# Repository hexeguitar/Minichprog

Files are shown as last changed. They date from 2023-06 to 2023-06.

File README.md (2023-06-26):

# Minichprog
### ESP32-S2 based programmer/debugger for the WCH CH32V003 series MCU.  
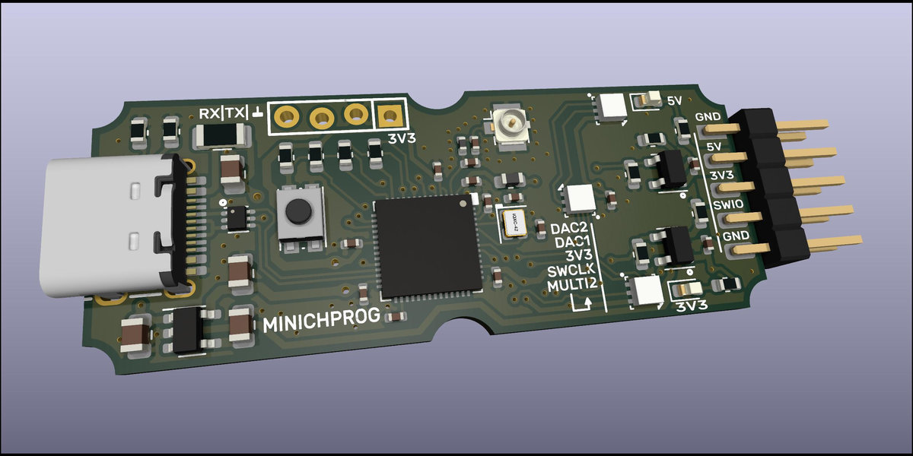
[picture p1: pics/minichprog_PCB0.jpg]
Minichprog
  
Hardware compatible with CNLohr's ESP32-S2 ch32v003 programmer:  
https://github.com/cnlohr/cnhardware/tree/master/esp32s2-funprog  
Firmware and flashing instructions availble here:  
https://github.com/cnlohr/esp32s2-cookbook/tree/master/ch32v003programmer

Differences:
- 500mA polyfuse on the VBUS rail
- USB protection IC
- Current limited power switches
- 5V and 3.3V present led indicators
- smaller footprint, fits into the "USB dongle" 
  acrylic enclosure (same as original WCHLinkE)
- U.FL connector for external WiFI antenna

PCB is 4 layer, designed using KiCAD7. Gerbers in ZIP file are included as well as HTML BOM.  

--- 
Pictures below show rev A, which had additional target discharge option. It was not necessary since the BL2555 power switches have that feature built in.
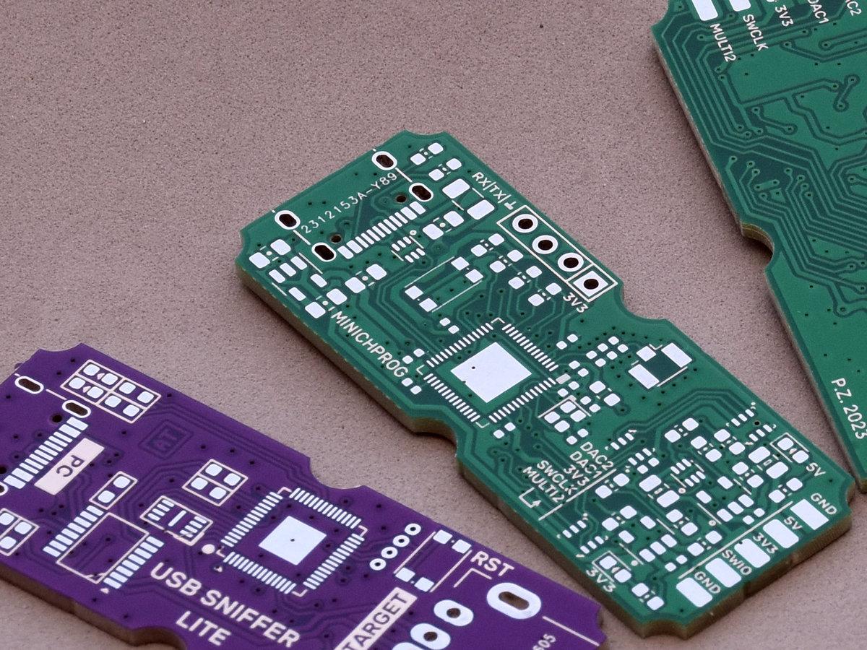
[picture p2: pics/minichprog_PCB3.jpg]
Minichprog

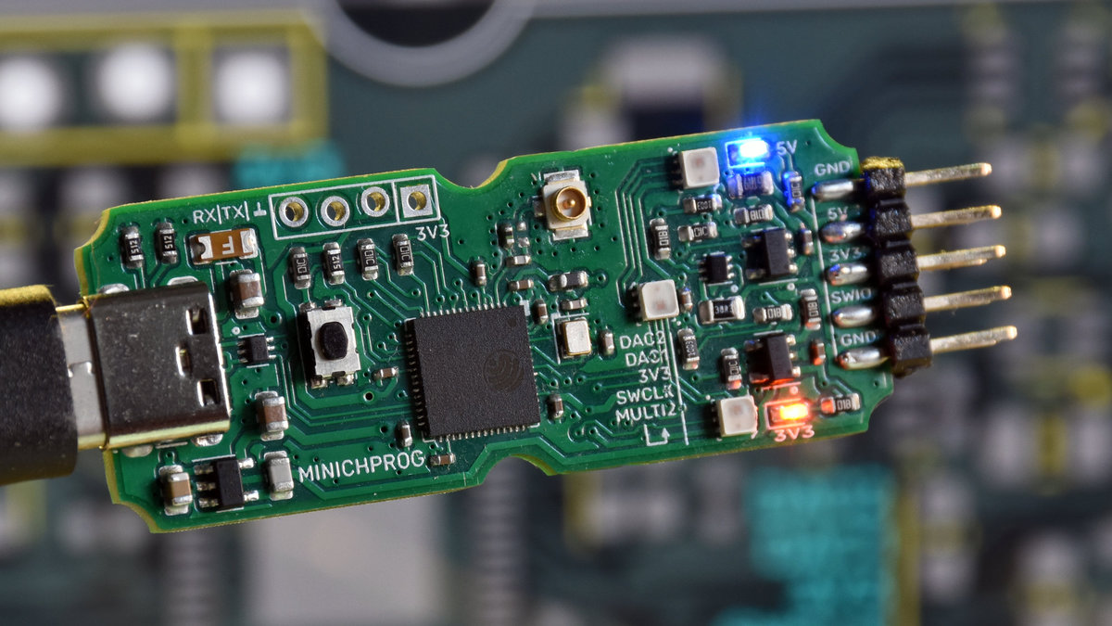
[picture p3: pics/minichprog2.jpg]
Minichprog
  

---  
PCB is designed to fit into one of those transparent "USB" enclosures, the same the original WCHLinkE programmer is using.  
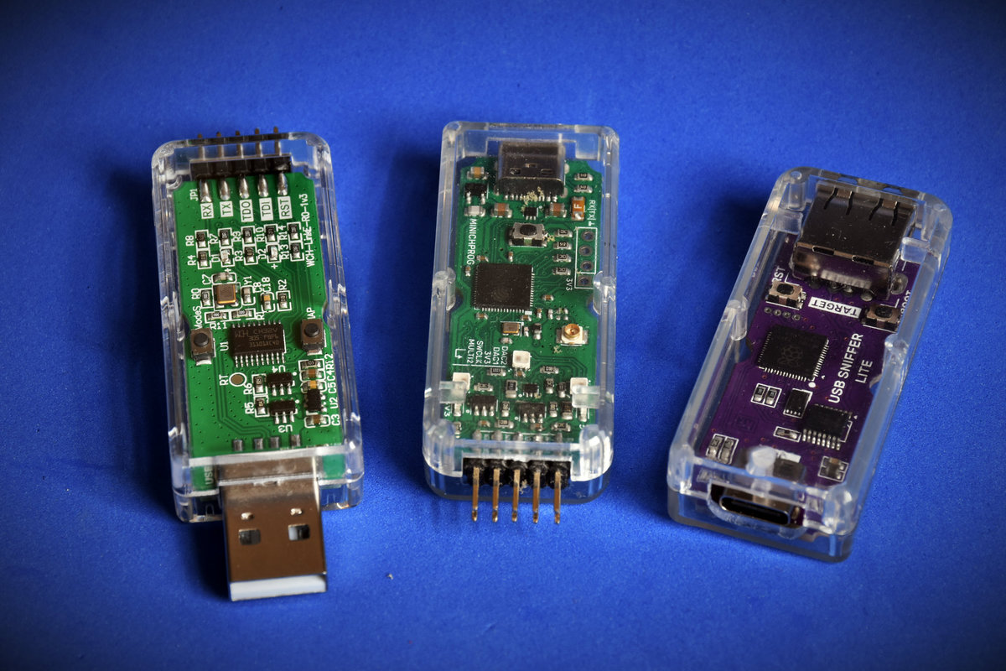
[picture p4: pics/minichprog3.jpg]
Minichprog
  

------
(c) 06.2023 by Piotr Zapart  
www.hexefx.com

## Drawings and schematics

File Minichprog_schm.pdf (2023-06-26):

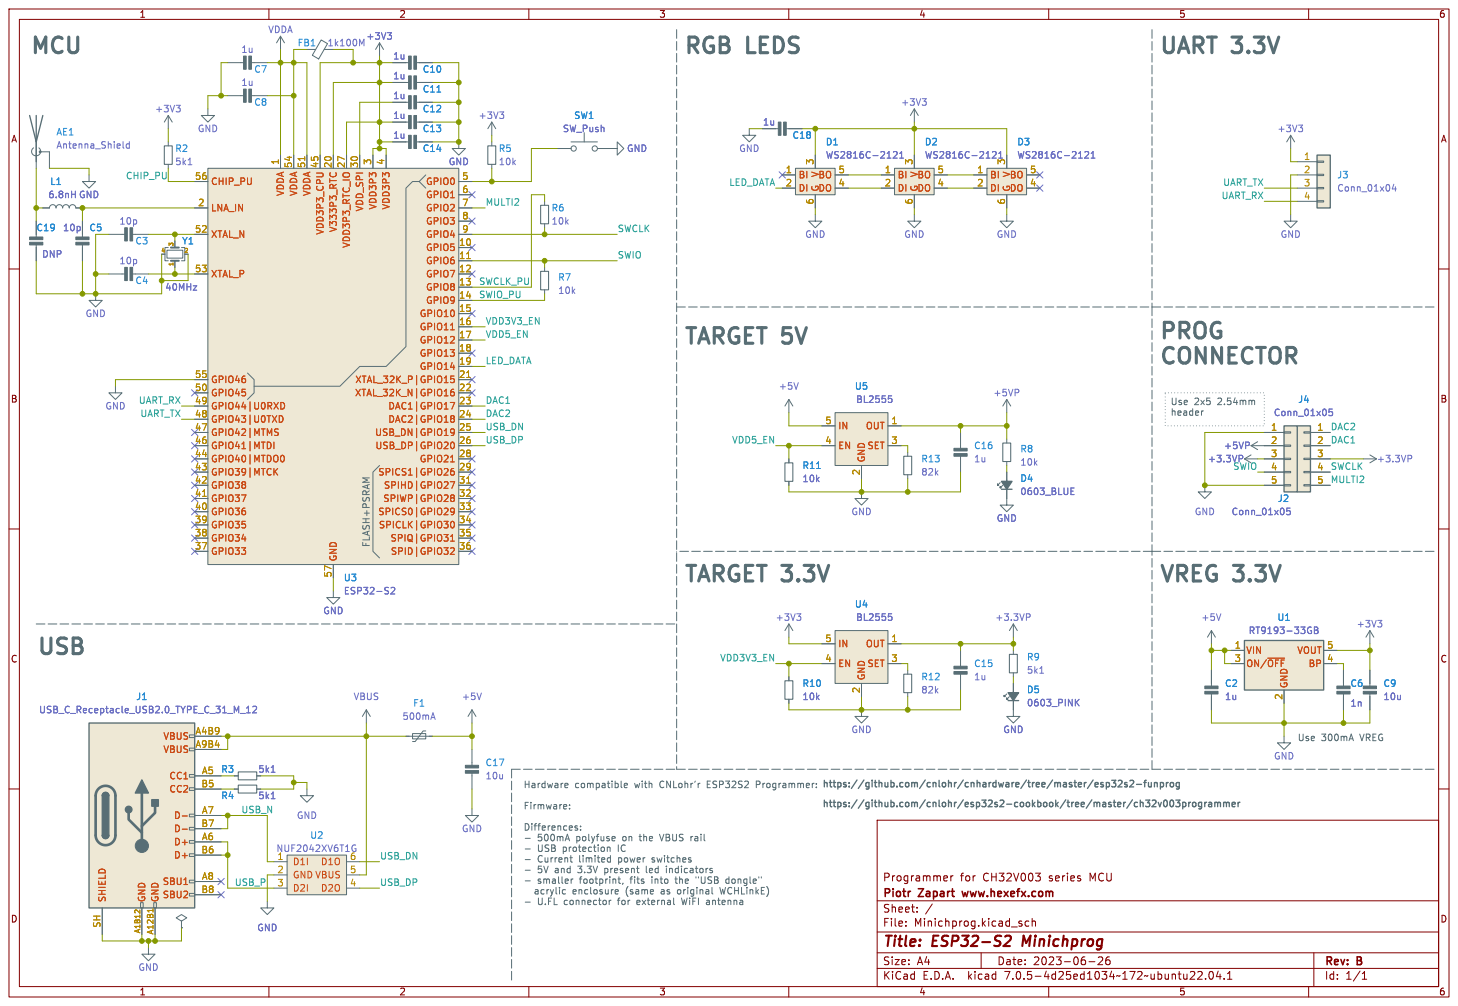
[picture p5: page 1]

2 ON/~{OFF} 3 BP 4 VOUT 5 U1 RT9193-33GB

2 ON/~{OFF} 3 BP 4 VOUT 5 C6

https://github.com/cnlohr/cnhardware/tree/master/esp32s2-funprog
https://github.com/cnlohr/esp32s2-cookbook/tree/master/ch32v003programmer

- 5V and 3.3V present led indicators

File: Minichprog.kicad_sch Sheet: / Piotr Zapart www.hexefx.com

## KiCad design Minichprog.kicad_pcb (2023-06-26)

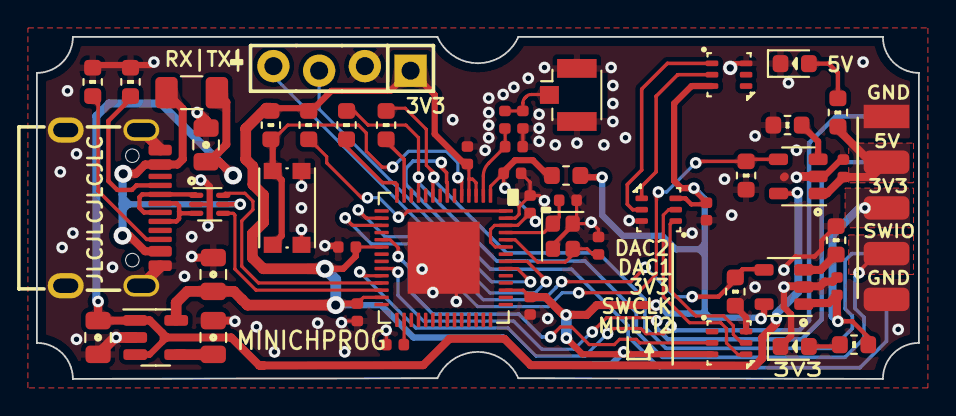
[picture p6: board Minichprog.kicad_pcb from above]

Board: 4 copper layers, 49.0 x 19.0 mm, 50 parts (1 on the bottom side), 41 nets.

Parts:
AE1: Antenna_Shield; U.FL_Hirose_U.FL-R-SMT-1_Vertical
C2: 1u; Hx_C_0805_2012Metric
C3, C4, C5: 10p; Hx_C_0402_1005Metric
C6: 1n; Hx_C_0805_2012Metric
C7, C8, C10, C11, C12, C13, C14, C15, C16, C18: 1u; Hx_C_0402_1005Metric
C9, C17: 10u; Hx_C_0805_2012Metric
C19: DNP; Hx_C_0402_1005Metric
D1, D2, D3: WS2816C-2121; WS2816-2121
D4: 0603_BLUE; LED_0603_1608Metric
D5: 0603_PINK; LED_0603_1608Metric
F1: 500mA; Fuse_1206_3216Metric
FB1: 1k100M; L_0603_1608Metric
J1: USB_C_Receptacle_USB2.0_TYPE_C_31_M_12; USB_C_TYPE-C-31-M-12
J2, J4: Conn_01x05; PinHeader_1x05_P2.54mm_SMDpads
J3: Conn_01x04; 1x4_254_offset
L1: 6.8nH; L_0402_1005Metric
R2, R3, R4, R9: 5k1; Hx_R_0603_1608Metric
R5, R6, R7, R8, R10, R11: 10k; Hx_R_0603_1608Metric
R12, R13: 82k; Hx_R_0603_1608Metric
SW1: SW_Push; SW_Push_1P1T_NO_CK_KMR2
U1: RT9193-33GB; SOT-23-5
U2: NUF2042XV6T1G; SOT-563
U3: ESP32-S2; QFN-56-1EP_7x7mm_P0.4mm_EP4x4mm
U4, U5: BL2555; SOT-23-5
Y1: 40MHz; Crystal_SMD_2016-4Pin_2.0x1.6mm

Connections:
+3.3VP: C15.2, J2.3, J4.3, R9.1, U4.1 (OUT)
+3V3: C9.2, C10.2, C11.2, C13.2, C14.2, C18.1, D1.3 (V), D2.3 (V), D3.3 (V), FB1.2, J3.1, R2.2, R5.2, U1.5 (VOUT), U3.3 (VDD3P3), U3.4 (VDD3P3), U3.20 (V333P3_RTC), U3.27 (VDD3P3_RTC_IO), U3.45 (VDD3P3_CPU), U4.5 (IN)
+5V: C2.2, C17.2, F1.2, U1.1 (VIN), U1.3 (ON/~OFF), U5.5 (IN)
+5VP: C16.2, J2.2, R8.1, U5.1 (OUT)
/CHIP_PU: R2.1, U3.56 (CHIP_PU)
/DAC1: J4.2, U3.23 (DAC1|GPIO17)
/DAC2: J4.1, U3.24 (DAC2|GPIO18)
/LED_DATA: D1.2 (DI), U3.19 (GPIO14)
/MULTI2: J4.5, U3.7 (GPIO2)
/SWCLK: J4.4, R6.1, U3.9 (GPIO4)
/SWCLK_PU: R6.2, U3.13 (GPIO8)
/SWIO: J2.4, R7.1, U3.11 (GPIO6)
/SWIO_PU: R7.2, U3.14 (GPIO9)
/UART_RX: J3.4, U3.49 (GPIO44|U0RXD)
/UART_TX: J3.3, U3.48 (GPIO43|U0TXD)
/USB_DN: U2.6 (D1O), U3.25 (USB_DN|GPIO19)
/USB_DP: U2.4 (D2O), U3.26 (USB_DP|GPIO20)
/USB_N: J1.A7 (D-), J1.B7 (D-), U2.1 (D1I)
/USB_P: J1.A6 (D+), J1.B6 (D+), U2.3 (D2I)
/VDD3V3_EN: R10.1, U3.16 (GPIO11), U4.4 (EN)
/VDD5_EN: R11.1, U3.17 (GPIO12), U5.4 (EN)
GND: AE1.2 (Shield), C2.1, C3.2, C4.2, C5.2, C6.1, C7.2, C8.2, C9.1, C10.1, C11.1, C12.1, C13.1, C14.1, C15.1, C16.1, C17.1, C18.2, C19.2, D1.6 (G), D2.6 (G), D3.6 (G), D4.1 (K), D5.1 (K), J1.A1B12 (GND), J1.A12B1 (GND), J1.SH (SHIELD), J2.1, J2.5, J3.2, R3.2, R4.2, R10.2, R11.2, R12.2, R13.2, SW1.2, U1.2 (GND), U2.2 (GND), U3.55 (GPIO46), U3.57 (GND), U4.2 (GND), U5.2 (GND), Y1.2, Y1.4
unnamed: AE1.1 (A), C19.1, L1.1
unnamed: D1.5 (BO), D2.1 (BI)
unnamed: D1.4 (DO), D2.2 (DI)
unnamed: D2.5 (BO), D3.1 (BI)
unnamed: D2.4 (DO), D3.2 (DI)
unnamed: D4.2 (A), R8.2
unnamed: D5.2 (A), R9.2
unnamed: J1.A5 (CC1), R3.1
unnamed: J1.B5 (CC2), R4.1
unnamed: C6.2, U1.4 (BP)
unnamed: R5.1, SW1.1, U3.5 (GPIO0)
unnamed: C5.1, L1.2, U3.2 (LNA_IN)
unnamed: C12.2, U3.30 (VDD_SPI)
unnamed: C3.1, U3.52 (XTAL_N), Y1.3
unnamed: C4.1, U3.53 (XTAL_P), Y1.1
unnamed: R12.1, U4.3 (SET)
unnamed: R13.1, U5.3 (SET)
VBUS: F1.1, J1.A4B9 (VBUS), J1.A9B4 (VBUS), U2.5 (VBUS)
VDDA: C7.1, C8.1, FB1.1, U3.1 (VDDA), U3.51 (VDDA), U3.54 (VDDA)
